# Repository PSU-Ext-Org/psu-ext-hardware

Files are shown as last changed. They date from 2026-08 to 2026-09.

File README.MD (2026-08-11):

<h1 align="center">PSU-EXT Hardware</h1>

<p align="center">
  An open-hardware inline extension that adds measurement, protection, and
  programmable control to an existing bench power supply.
</p>

<p align="center">
  
  
  
  
</p>

> **EVT prototype:** PSU-EXT is an engineering-validation design, not a
> finished or certified consumer product. It extends a bench PSU; it is not a
> standalone power supply. Use it only within the stated ratings and with
> appropriate laboratory safety practices.

<p align="center">
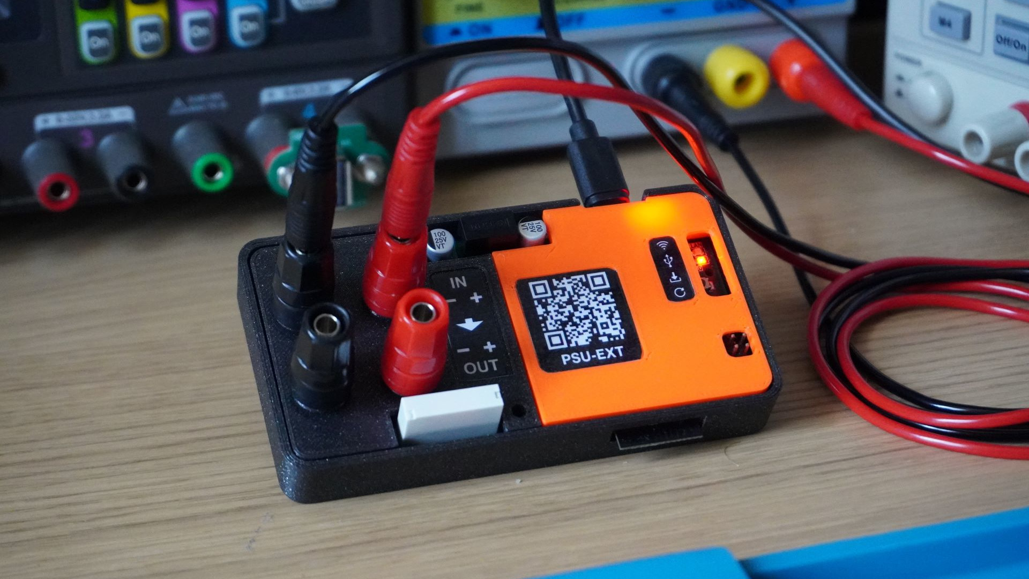
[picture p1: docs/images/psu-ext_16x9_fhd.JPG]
PSU-EXT prototype
  
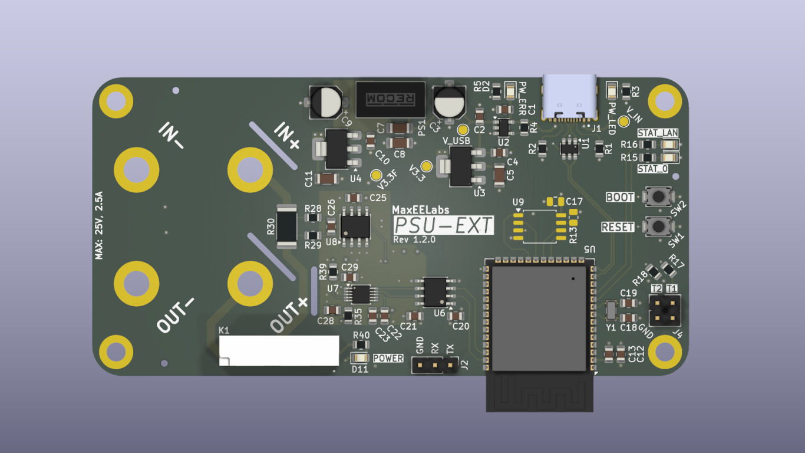
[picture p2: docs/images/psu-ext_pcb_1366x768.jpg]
PSU-EXT PCB render
  
</p>

## What it does

PSU-EXT sits between a bench power supply and a load or device under test. It
measures output voltage and current, controls the output path with a relay, and
makes the setup easier to monitor and automate.

- Live voltage, current, and power telemetry
- Relay-controlled output enable/disable
- Galvanically isolated control and measurement domains
- SCPI control over USB CDC and TCP through the companion firmware and software
- External trigger inputs, timer support, and configurable OVP/OCP behaviour

## Hardware at a glance

> **Warning:** PSU-EXT does not provide reverse-polarity protection. Verify
> supply and load polarity before connecting the device.

| Item | Details |
| --- | --- |
| Operating range | 0–25 V, 0–2.5 A |
| Board size | 100 × 50 mm (3.94 × 1.97 in) |
| Control connection | USB-C for power and data |
| Controller | Espressif ESP32-S3 |
| Measurement | ADS1115 ADC and INA240 current-sense front end |
| Isolation | Isolated I²C and isolated DC-DC power for the measurement domain |

## Repository contents

- [`electronics/`](electronics/) — KiCad schematics, PCB, libraries, and the
  [schematic PDF export](electronics/exports/schematic.pdf)
- [`mechanical/`](mechanical/) — FreeCAD enclosure design and label artwork
- [`manufacturing/`](manufacturing/) — Gerbers, BOM, and pick-and-place (CPL)
  files for fabrication and assembly
- [`THIRD-PARTY-NOTICES.md`](THIRD-PARTY-NOTICES.md) — attribution and licence
  information for bundled library assets

The design was created with [**FreeCAD 1.1.1**](https://www.freecad.org/) and
[**KiCad 10.0.1**](https://www.kicad.org/).

## Related PSU-EXT projects

- [PSU-EXT Root](https://github.com/PSU-Ext-Org/psu-ext)
- [Firmware](https://github.com/PSU-Ext-Org/psu-ext-firmware)
- [Control software](https://github.com/PSU-Ext-Org/psu-ext-software)

## Licence

Original PSU-EXT hardware design sources are licensed under the
[CERN Open Hardware Licence Version 2 - Strongly Reciprocal](LICENCE)
(CERN-OHL-S v2). The source location is
<https://github.com/PSU-Ext-Org/psu-ext>.

Some library assets are separately licensed. See [NOTICE](NOTICE),
[THIRD-PARTY-NOTICES.md](THIRD-PARTY-NOTICES.md), and
[LICENSES/dep5](LICENSES/dep5) before copying or modifying them.

Changes to the design are recorded in [CHANGES.txt](CHANGES.txt).

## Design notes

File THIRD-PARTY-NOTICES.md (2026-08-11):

# Third-Party Notices

This document identifies library assets that are not licensed under CERN-OHL-S
v2. They remain under their stated licences. The PSU-EXT KiCad design that uses
these assets is licensed under CERN-OHL-S v2.

## OSHW gear-logo bundle

| Files | Copyright and source | Licence |
|---|---|---|
| `electronics/lib/external/footprints-oshw.pretty/logo_oshw_22x13.2mm.kicad_mod` | Macklin Chaffee, 2011. [Open Source Hardware Logo — OSHWA](https://oshwa.org/resources/open-source-hardware-logo/) | [CC BY-SA 4.0](https://creativecommons.org/licenses/by-sa/4.0/) |

The OSHW gear logo may be used only for hardware that complies with the Open
Source Hardware Definition. It is not the OSHWA Certification Mark.

## SnapEDA / SnapMagic bundles

The four bundles below contain nine distributed SnapMagic Design Files: one
shared KiCad symbol-library file, four footprint files, and four STEP model
files. This repository must not add another SnapMagic Design File without prior
written permission from SnapMagic.

All listed SnapMagic Design Files are licensed under
[CC BY-SA 4.0](https://creativecommons.org/licenses/by-sa/4.0/) with the
[SnapMagic Design Exception 1.0](https://www.snapeda.com/about/terms/).
Attribution: SnapMagic Search and the applicable component manufacturer. The
Design Exception permits the combined PSU-EXT circuit-board design to be
conveyed under CERN-OHL-S v2; it does not relicense the library files.

| Bundle | Symbol | Footprint | 3D model | Source |
|---|---|---|---|---|
| Epson FC-135 32.7680KA-A0 | `electronics/lib/external/symbols-snapeda.kicad_sym` | `electronics/lib/external/footprints-snapeda.pretty/XTAL_FC-135_32.7680KA-A0.kicad_mod` | `electronics/lib/external/models-snapeda/FC-135_32.7680KA-A0.step` | <https://www.snapeda.com/parts/FC-135%2032.7680KA-A0/Epson/view-part/?ref=snap> |
| Hongfa HF49FD/005-1H12T | `electronics/lib/external/symbols-snapeda.kicad_sym` | `electronics/lib/external/footprints-snapeda.pretty/RELAY_HF49FD_005-1H12T.kicad_mod` | `electronics/lib/external/models-snapeda/005-1H12T-3DModel-STEP-56544.step` | <https://www.snapeda.com/parts/HF49FD/005-1H12T/Hongfa/view-part/?ref=snap> |
| RECOM RFM-0505S | `electronics/lib/external/symbols-snapeda.kicad_sym` | `electronics/lib/external/footprints-snapeda.pretty/CONV_RFM-0505S.kicad_mod` | `electronics/lib/external/models-snapeda/RFM-0505S.step` | <https://www.snapeda.com/parts/RFM-0505S/Recom+Power/view-part/?ref=snap> |
| HRO TYPE-C-31-M-12 | `electronics/lib/external/symbols-snapeda.kicad_sym` | `electronics/lib/external/footprints-snapeda.pretty/HRO_TYPE-C-31-M-12.kicad_mod` | `electronics/lib/external/models-snapeda/TYPE-C-31-M-12.step` | <https://www.snapeda.com/parts/TYPE-C-31-M-12/HRO+Electronics+Co.%252C+Ltd./view-part/?ref=snap> |

## MaxEELabs logo bundle

`electronics/lib/external/footprints-maxeelabs.pretty/logo_20x11.2mm.kicad_mod`
is original work of Maxim Pavlov and is excluded from CERN-OHL-S v2. It is
proprietary, with all rights reserved; no permission is granted to use, copy,
modify, distribute, or otherwise exploit the logo, subject only to rights that
cannot be excluded by law. This restriction applies only to the logo asset and
does not restrict the CERN-OHL-S v2 rights in the separate technical design
source. See the `proprietary/maxeelabs-logo` block in `LICENSES/dep5`.

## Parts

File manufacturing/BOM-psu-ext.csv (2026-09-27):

*Reference | *Manufacturer Part number | *QTY | *Original | Description | Purchase Link
R29 | 0805W8F470JT5E | 1 | Y | 47Ω ±1% 125mW 0805 Thick Film Resistor
R34 | 0805W8F1501T5E | 1 | Y | 1.5kΩ ±1% 125mW 0805 Thick Film Resistor
C10,C13,C15,C2,C20,C22,C23,C24,C26,C27,C28,C32,C33,C34,C4 | CC0805KRX7R9BB104 | 15 | Y | 100nF ±10% 50V Ceramic Capacitor X7R 0805
R35 | 0805W8F100JT5E | 1 | Y | 10Ω ±1% 125mW 0805 Thick Film Resistor
R10,R11,R18,R28,R5 | 0805W8F1002T5E | 5 | Y | 10kΩ ±1% 125mW 0805 Thick Film Resistor
R25 | 25121WF100MT4E | 1 | Y | 10mΩ 1W 200V Thick Film Resistor ±1500ppm/℃ ±1% 2512 Chip Resistor - Surface Mount RoHS
C30,C31 | CL21B103KBANNNC | 2 | Y | 10nF ±10% 50V Ceramic Capacitor X7R 0805
C11,C5 | CL31A106KBHNNNE | 2 | Y | 10uF ±10% 50V Ceramic Capacitor X5R 1206
C12,C36,C6 | CL21A106KAYNNNE | 3 | Y | 10uF ±10% 25V Ceramic Capacitor X5R 0805
C14,C18 | CC0805JRNPO9BN120 | 2 | Y | 12pF ±5% 50V Ceramic Capacitor NP0 0805
R36,R37,R38,R39 | FRC0805J164 TS | 4 | Y | 160kΩ ±5% 125mW 0805 Thick Film Resistor
R3,R32,R4,R44,R45,R8,R9 | 0805W8F1001T5E | 7 | Y | 1kΩ ±1% 125mW 0805 Thick Film Resistor
C21 | CL21B102KBCNNNC | 1 | Y | 1nF ±10% 50V Ceramic Capacitor X7R 0805
C1,C16 | CL21B105KBFNNNE | 2 | Y | 1uF ±10% 50V Ceramic Capacitor X7R 0805
R40,R41,R42,R43 | 0805W8F2002T5E | 4 | Y | 20kΩ ±1% 125mW 0805 Thick Film Resistor
C29 | CL21B224KBFNNNE | 1 | Y | 220nF ±10% 50V Ceramic Capacitor X7R 0805
R14,R15,R16,R17,R21,R22 | 0805W8F220JT5E | 6 | Y | 22Ω ±1% 125mW 0805 Thick Film Resistor
R30 | 0805W8F2202T5E | 1 | Y | 22kΩ ±1% 125mW 0805 Thick Film Resistor
C35,C37,C38 | CL21A226MAQNNNE | 3 | Y | 22uF ±20% 25V Ceramic Capacitor X5R 0805
R31 | 0805W8J0202T5E | 1 | Y | 2kΩ ±5% 125mW 0805 Thick Film Resistor
R33 | 0805W8F3300T5E | 1 | Y | 330Ω ±1% 125mW 0805 Thick Film Resistor
C7,C8 | TCC1206COG331J102DT | 2 | Y | 330pF ±5% 1kV Ceramic Capacitor C0G 1206
R23,R24 | 0805W8F470KT5E | 2 | Y | 4.7Ω ±1% 125mW 0805 Thick Film Resistor
R12,R13,R26,R27,R6,R7 | 0805W8F4701T5E | 6 | Y | 4.7kΩ ±1% 125mW 0805 Thick Film Resistor
C3,C9 | 189RV0006 | 2 | Y | 47uF ±20% 35V Aluminum Electrolytic Capacitors 2000hrs@105℃
R1,R2 | 0805W8F5101T5E | 2 | Y | 5.1kΩ ±1% 125mW 0805 Thick Film Resistor
U8 | ADS1115IDGST | 1 | Y | I2C 2V~5.5V VSSOP-10-0.5mm Analog to Digital Converters (ADC) RoHS
U2 | AP22818BKCWT-7 | 1 | Y | 1 Active Low 2A High Side Switch TSOT-23-5 Power Distribution Switches, Load Drivers RoHS
J3 | 2.54-1*3P | 1 | Y | Pin Header 3 Position 2.54mm Pitch Single Row Through Hole -40℃~+105℃
J2 | 2.54-2*3P | 1 | Y | Pin Header 6 Position 2.54mm Pitch Dual Row Through Hole
D5,D6,D7,D8 | ESD5Z3.3T1G | 4 | Y | 14VC Clamp 11A Ipp ESD DIODE SOD-523
U5 | ESP32-S3-WROOM-1-N16R8 | 1 | Y | 2.4GHz ESP32-S3R8 On-board PCB Antenna -103.5dBm SMD,25.5x18mm RF Transceiver Modules and Modems RoHS
Y1 | FC-135R 32.7680KA-A3 | 1 | Y | Crystal 32.768kHz ±20ppm 12.5pF 50kΩ SMD3215-2P
K1 | HF49FD/005-1H12T | 1 | Y | Power Relay 1 Form A: 1A (SPST-NO) 5V Coil SIP,5x20mm
U10 | INA240A2DR | 1 | Y | 1 5uV -4V~80V 2V/us 132dB 90uA 1.8mA 50V/V SOIC-8 Instrumentation, Op Amps, Buffer Amps RoHS
U7 | ISO1540DR | 1 | Y | 50kV/us 3V~5.5V SOIC-8 Digital Isolators RoHS
U3,U4 | LD1117S33TR | 2 | Y | 3.3V Positive Fixed SOT-223 Voltage Regulators - Linear, Low Drop Out (LDO) Regulators RoHS
D3 | KT-0805G | 1 | Y | Emerald Green 525nm LED Indication - Discrete 2.6V~3.1V 0805
D4 | KT-0805W | 1 | Y | White LED Indication - Discrete 2.6V~3.2V 0805
D1,D14,D2 | NCD0805R1 | 3 | Y | Red 630nm LED Indication - Discrete 1.6V~2.6V 0805
D15 | LL4148-GS08 | 1 | Y | Diode Independent 75V 300mA Surface Mount MiniMELF
U12 | LM2664M6X/NOPB | 1 | Y | Inverted 80kHz -5.5V~-1.8V 40mA SOT-23-6 Voltage Regulators - DC DC Switching Regulators RoHS
U9 | LMV321LILT | 1 | Y | 70mA 1 7mV 600V/ms 75dB 27nA 120uA 1.3MHz Rail-to-rail output SOT-23-5 Instrumentation, Op Amps, Buffer Amps RoHS
Q1 | MMBT2222A 1P | 1 | Y | Bipolar (BJT) Transistor NPN 40V 600mA 300MHz 300mW Surface Mount SOT-23
PS1 | RFM-0505S | 1 | Y | Isolated Module DC DC Converter 1 Output 5V 200mA 5V Input
D13 | SMBJ36A | 1 | Y | 58.1VC Clamp 10.4A@10/1000us Ipp TVS DIODE DO-214AA(SMB)
SW1,SW2 | TS-1088-AR02016 | 2 | Y | Tactile Switch SPST 160gf 2mm SMD (SMT) Tab 4mm x 3mm Surface Mount
U11 | TSZ122IYDT | 1 | Y | 7mA 2 1uV 0.19V/us 122dB 70pA 28uA 400kHz Rail-to-Rail Input, Rail-to-Rail Output SO-8 Instrumentation, Op Amps, Buffer Amps RoHS
J1 | TYPE-C-31-M-12 | 1 | Y | USB-C (USB TYPE-C) Receptacle Connector 16 Position Surface Mount
U1 | USBLC6-2SC6 | 1 | Y | 15VC Clamp ESD DIODE SOT-23-6

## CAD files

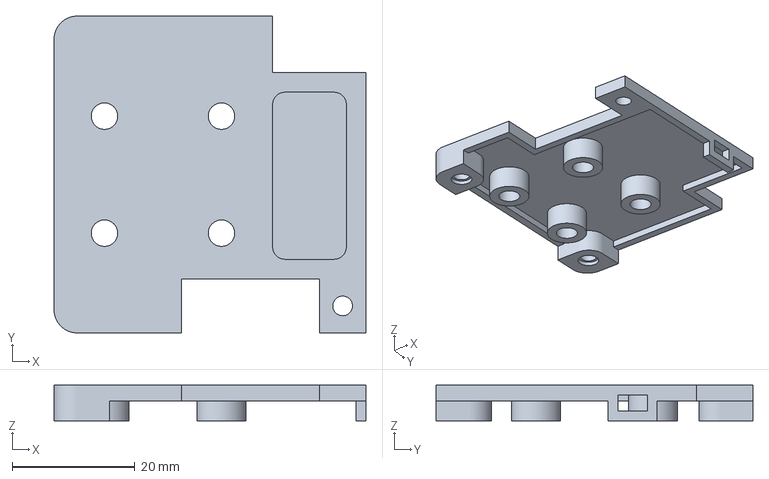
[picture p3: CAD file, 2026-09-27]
mechanical/enclosure/exports/housingcover-top-right.3mf
50.8 x 51.6 x 5.80 mm

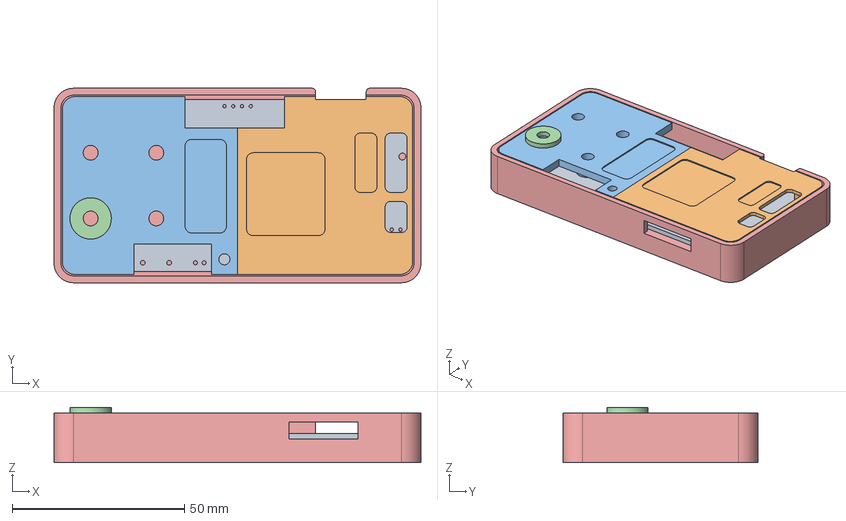
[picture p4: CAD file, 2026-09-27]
mechanical/enclosure/psu-ext-enclosure.FCStd
106.4 x 56.4 x 16.0 mm
Pcb_f07c
cover-top-left
cover-top-right
terminal-nut
bs-joined-frame-bottom

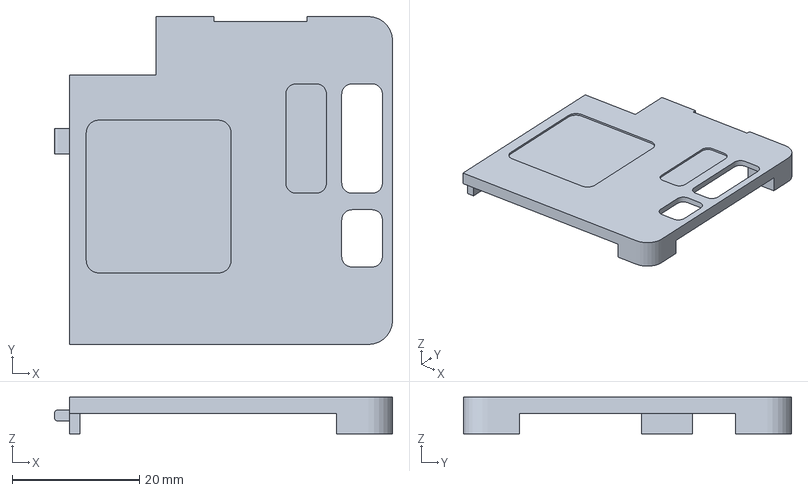
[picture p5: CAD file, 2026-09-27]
mechanical/enclosure/exports/housingcover-top-left.3mf
53.2 x 51.6 x 5.80 mm

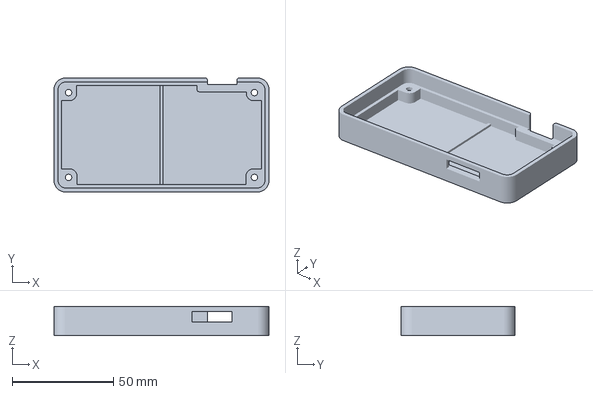
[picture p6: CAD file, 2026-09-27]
mechanical/enclosure/exports/bs-joined-frame-bottom.3mf
106.4 x 56.4 x 14.4 mm

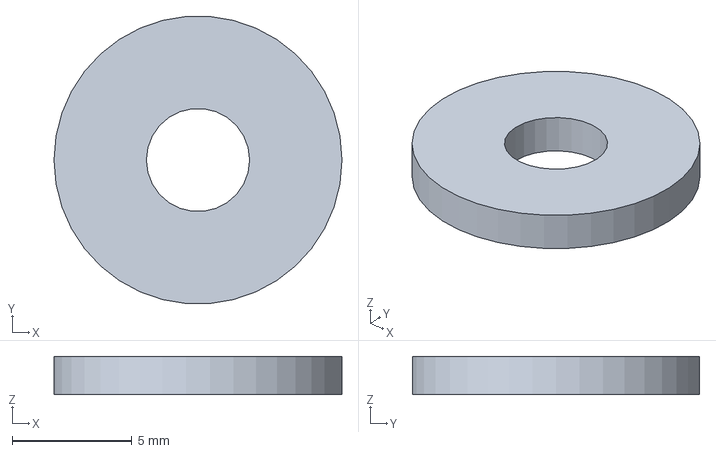
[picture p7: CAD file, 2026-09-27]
mechanical/enclosure/exports/terminal-nut.3mf
12.0 x 12.0 x 1.60 mm

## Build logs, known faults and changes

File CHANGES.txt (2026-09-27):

PSU-EXT change record
=====================

When publishing a modification, add (do not remove) a dated, brief description
of each design change. This supports CERN-OHL-S v2 section 3.3(b).

2026-08-09 v. 1.2.0: Added repository licensing, ownership, and third-party dependency
notices for the public CERN-OHL-S v2 release.

2026-08-15 v. 1.2.1: 
- Added low impedance offset to INA240A2, using resistor divider and
LM321, small offset would allow correct current measurments between 0 and 5 mA, alternativelty
by seting offset to 3V one can measure current into 2 directions but with less resolution.
- Marked C16 - IO0 debounce cap as do-not-populate as it forces ESP32 into download mode on 
first start

2026-09-09 v. 1.3.0 (work in progress):
- Added input buffering and a negative rail for near-zero measurements.
- Split the front end into ADC/current and voltage schematic sheets and updated
  the PCB and project configuration.
- Added the MaxEELabs symbol library, with copyright and CERN-OHL-S v2 license
  information recorded separately in LICENSES/dep5.

Work in progress: the generated outputs still need to be updated.
- TODO: Update the BOM.
- TODO: Update the CPL (pick-and-place file).
- TODO: Update the schematic export.
- TODO: Update the Gerbers.

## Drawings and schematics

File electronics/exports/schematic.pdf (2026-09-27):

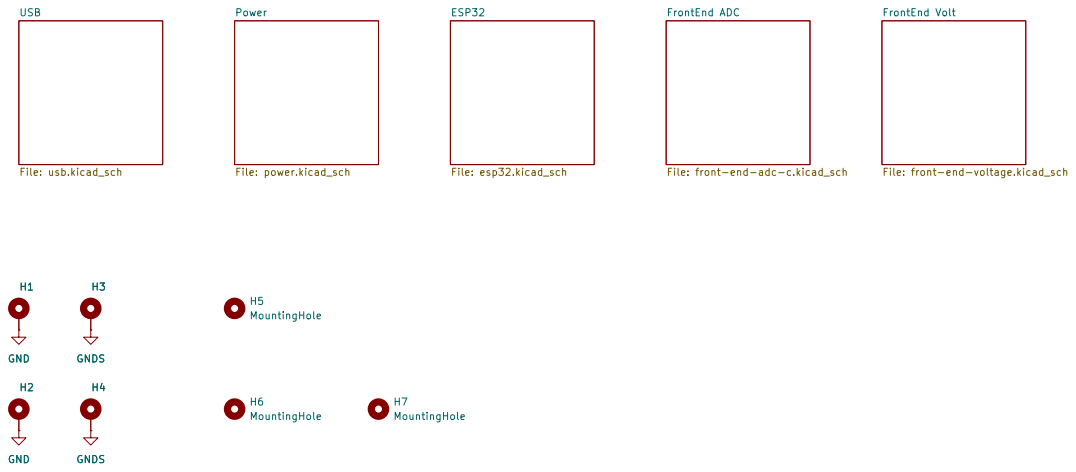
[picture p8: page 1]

File: front-end-adc-c.kicad_sch Power File: power.kicad_sch USB

FrontEnd Volt File: front-end-voltage.kicad_sch

This hardware design is licensed under CERN-OHL-S v2.
Copyright © 2026 PSU-EXT Authors: https://github.com/PSU-Ext-Org

MaxEELabs
Sheet: /
File: psu-ext.kicad_sch
Title: PSU-EXT Root

Size: A4 | Rev: 1.3.0
KiCad E.D.A. 10.0.6 | Id: 1/6

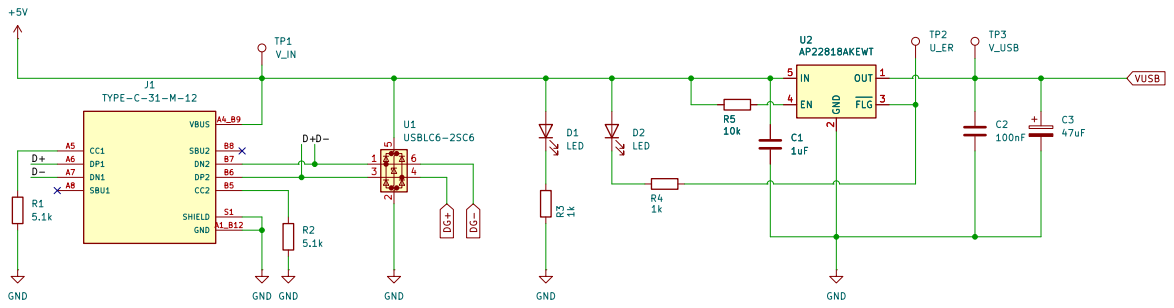
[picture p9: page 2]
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

MaxEELabs
Sheet: /USB/
File: usb.kicad_sch
Title: PSU-EXT USB

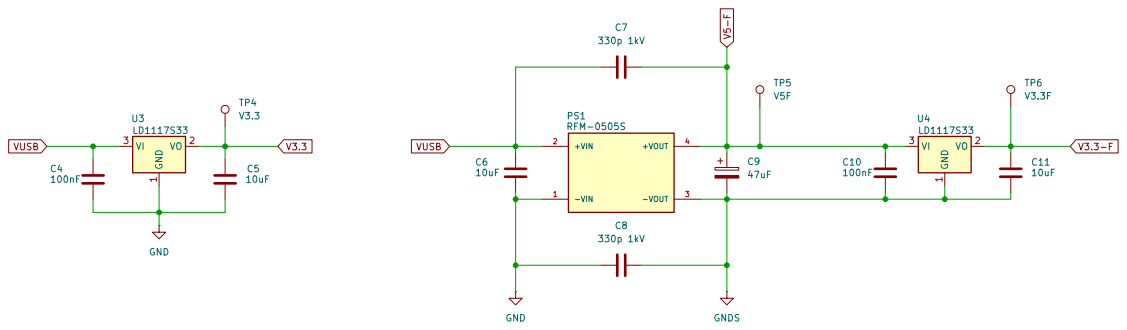
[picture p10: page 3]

Copyright © 2026 PSU-EXT Authors: https://github.com/PSU-Ext-Org GND
10uF GND

This hardware design is licensed under CERN-OHL-S v2.

MaxEELabs
Sheet: /Power/
File: power.kicad_sch
Title: PSU-EXT Power

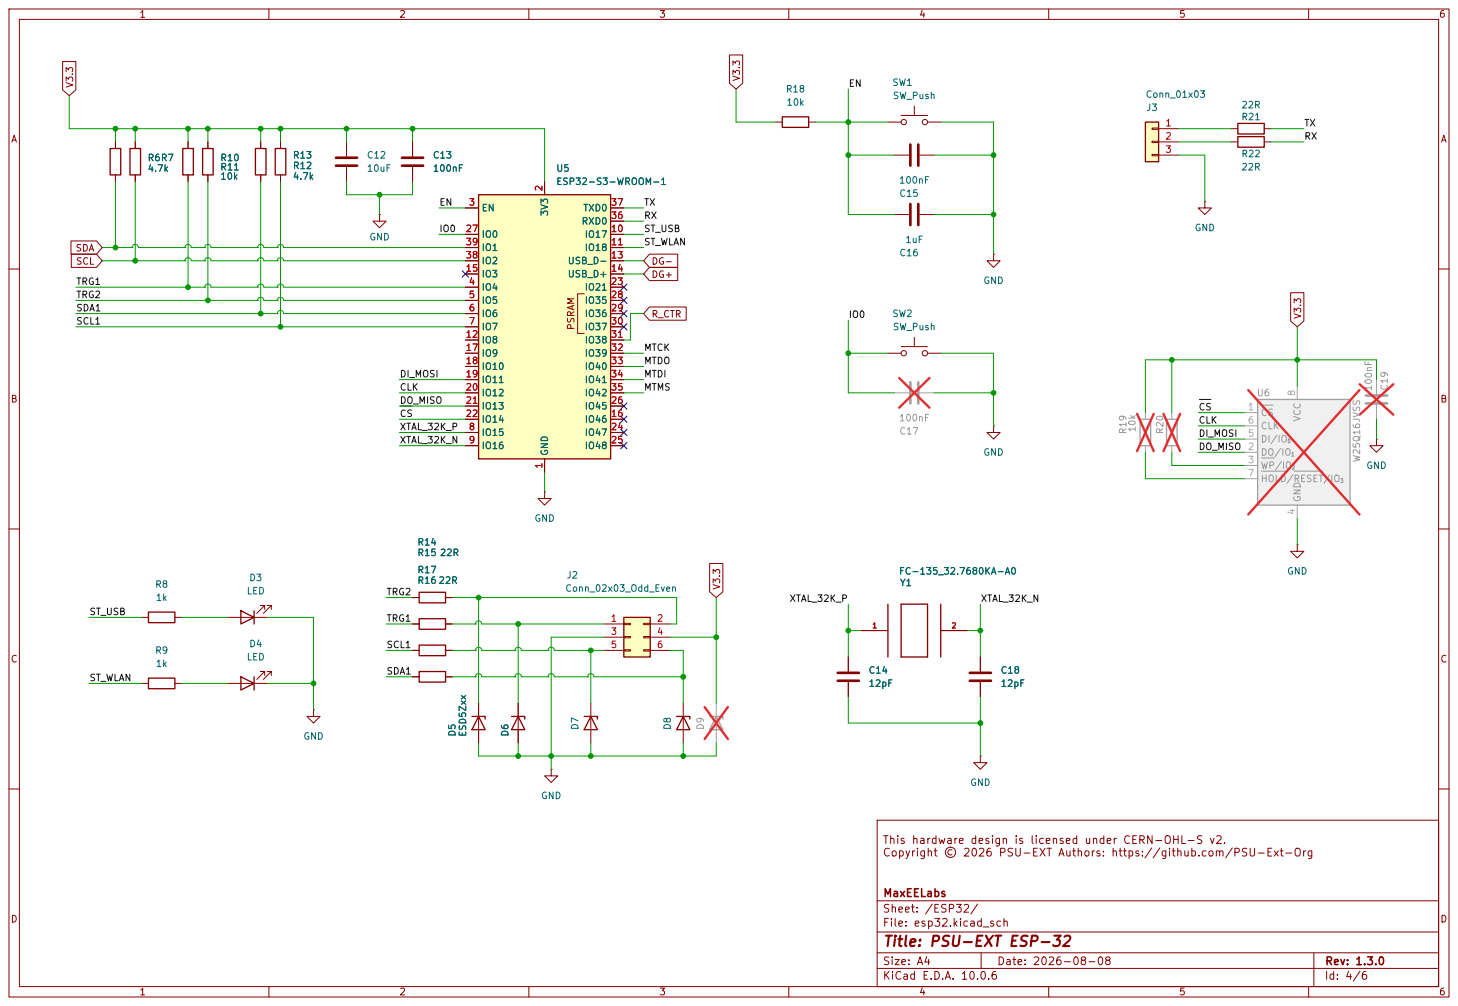
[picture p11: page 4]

4 DI/IO0 5 CLK 6 HOLD/RESET/IO3 7 VCC U6 8 W25Q16JVSS

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

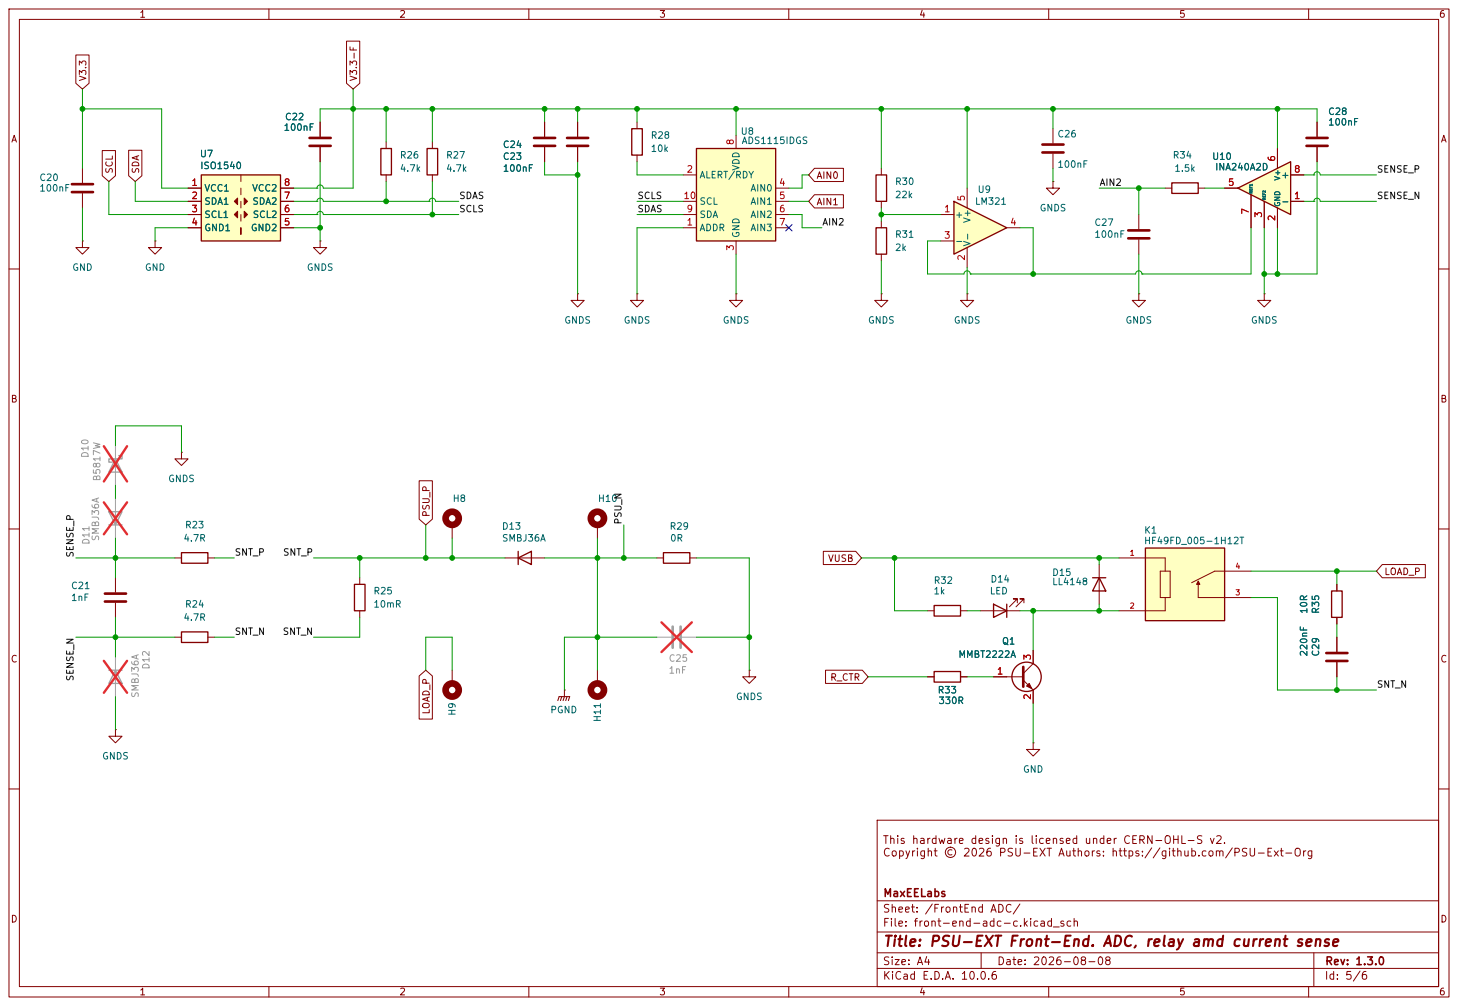
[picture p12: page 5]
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

MaxEELabs
Sheet: /FrontEnd ADC/
File: front-end-adc-c.kicad_sch
Title: PSU-EXT Front-End. ADC, relay amd current sense

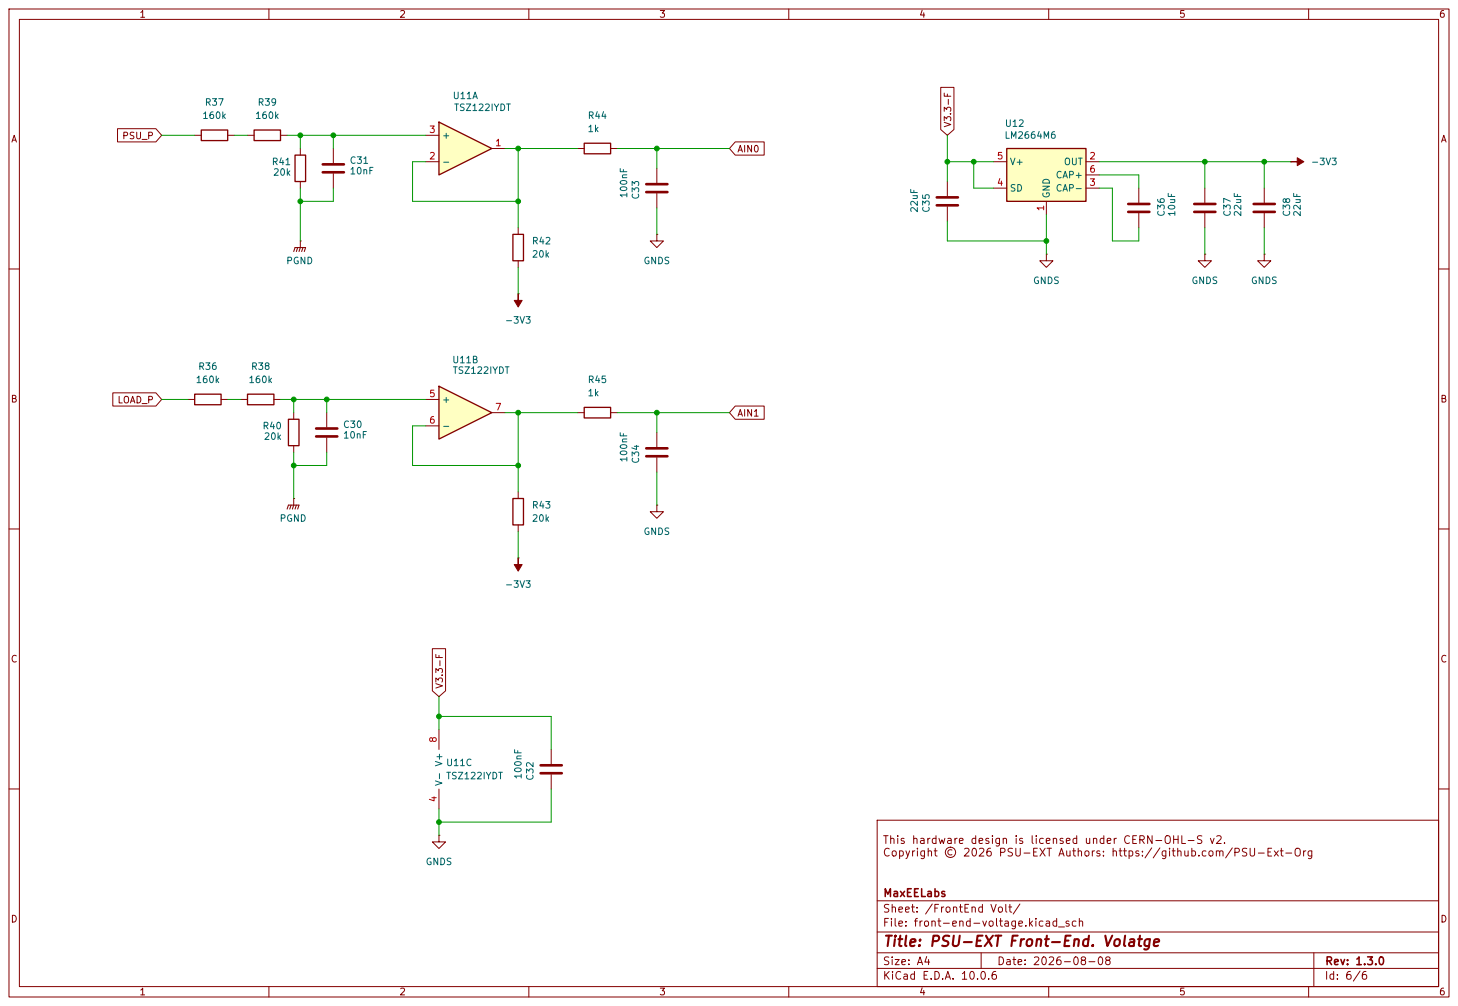
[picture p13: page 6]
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

MaxEELabs
Sheet: /FrontEnd Volt/
File: front-end-voltage.kicad_sch
Title: PSU-EXT Front-End. Volatge

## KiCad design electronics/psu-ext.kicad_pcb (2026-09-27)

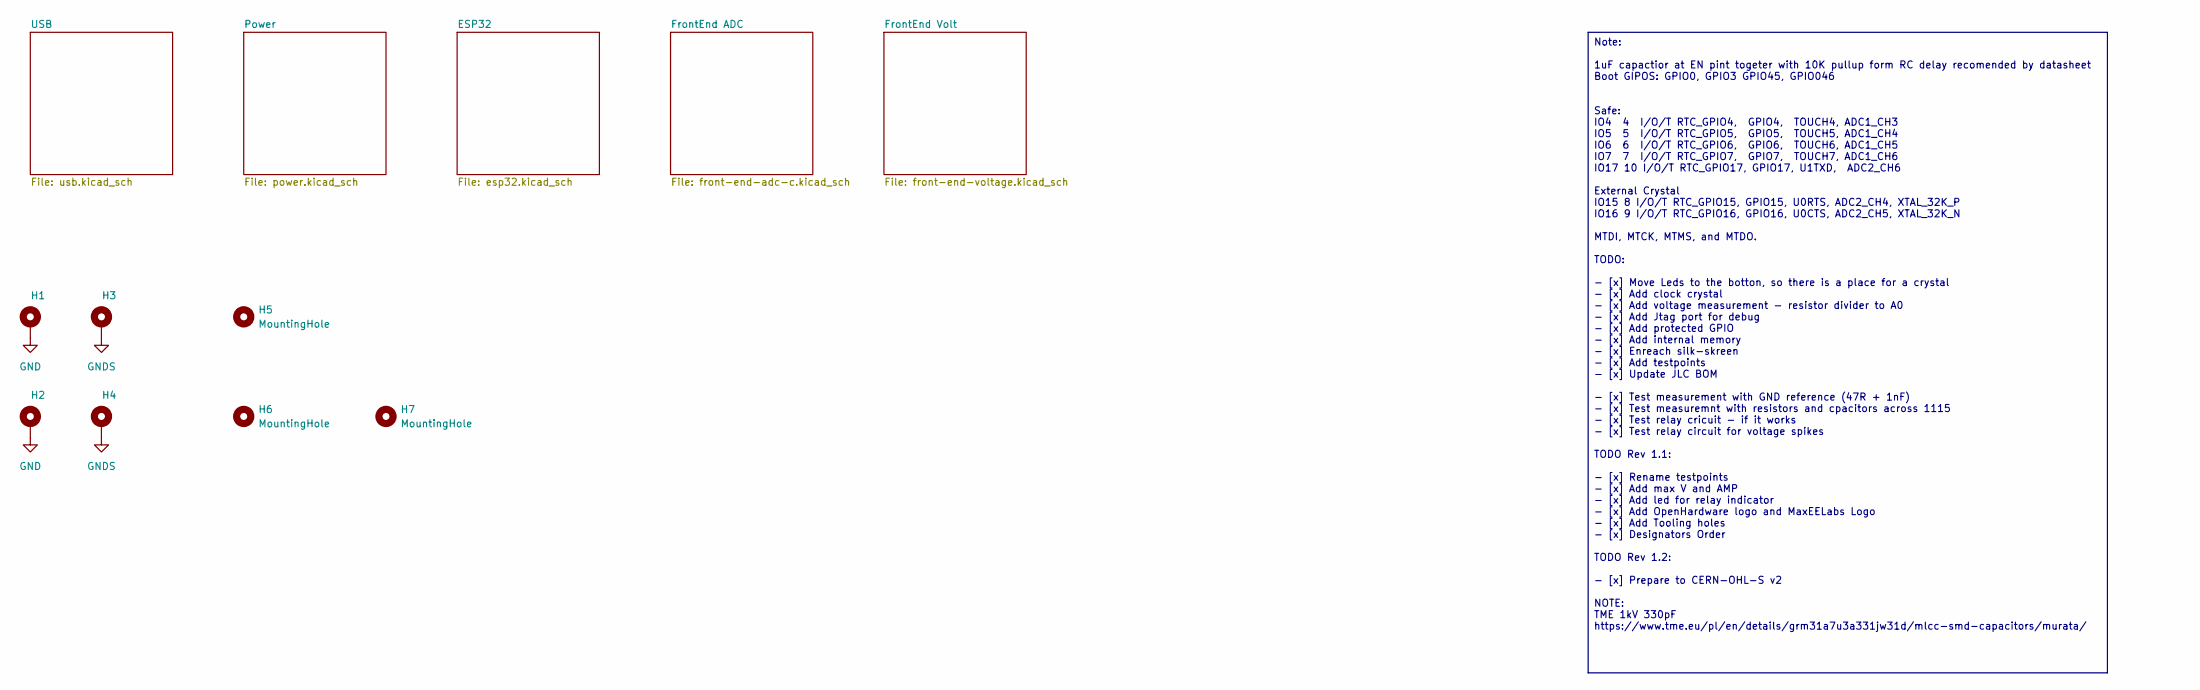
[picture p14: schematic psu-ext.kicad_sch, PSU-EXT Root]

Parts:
H1, H2, H3, H4: MountingHole_Pad; MountingHole_3.2mm_M3_ISO7380_Pad
H5, H6, H7: MountingHole; ToolingHole_1.152mm

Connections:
GND: H1.1 (1_1), H2.1 (1_1); also elsewhere on the board
GNDS: H3.1 (1_1), H4.1 (1_1); also elsewhere on the board

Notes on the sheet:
Note: 1uF capactior at EN pint togeter with 10K pullup form RC delay recomended by datasheet Boot GIPOS: GPIO0, GPIO3 GPIO45, GPIO046 Safe: IO4 4 I/O/T RTC_GPIO4, GPIO4, TOUCH4, ADC1_CH3 IO5 5 I/O/T RTC_GPIO5, GPIO5, TOUCH5, ADC1_CH4 IO6 6 I/O/T RTC_GPIO6, GPIO6, TOUCH6, ADC1_CH5 IO7 7 I/O/T RTC_GP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

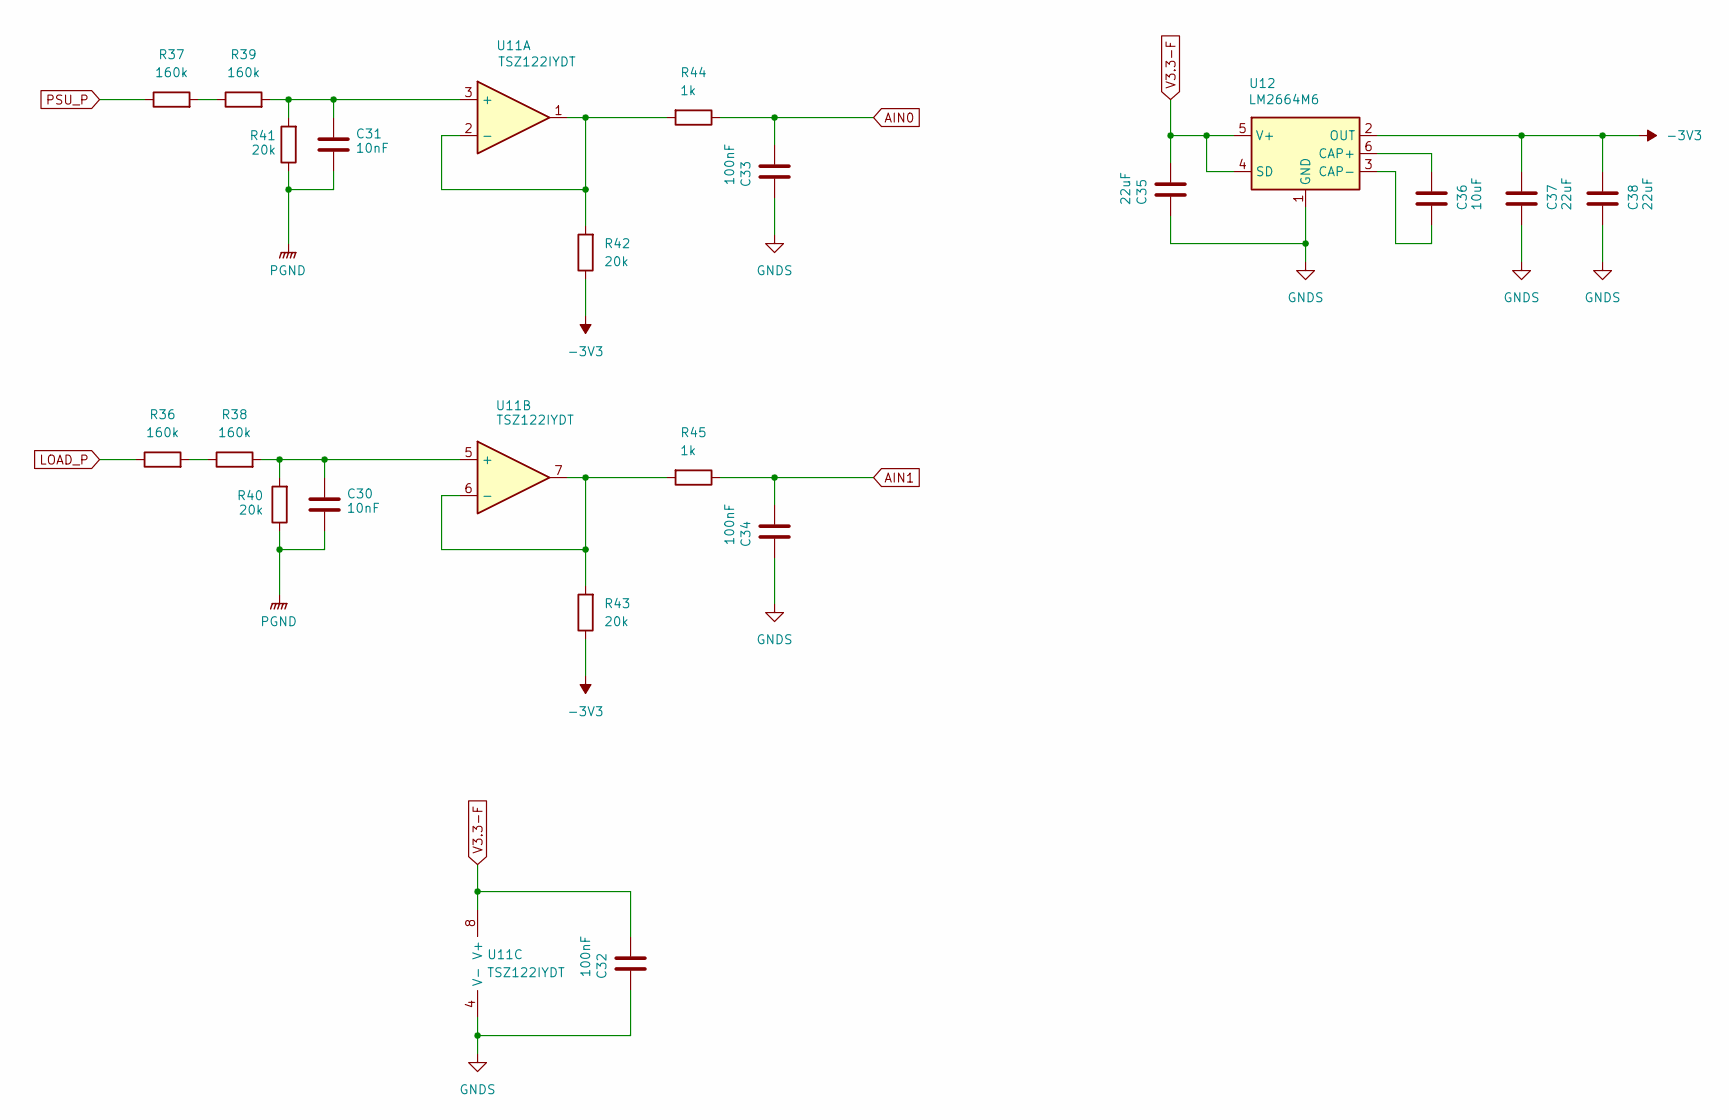
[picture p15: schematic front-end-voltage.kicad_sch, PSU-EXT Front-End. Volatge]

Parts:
C30, C31: 10nF; C_0805_2012Metric
C32, C33, C34: 100nF; C_0805_2012Metric
C35, C37, C38: 22uF; C_0805_2012Metric
C36: 10uF; C_0805_2012Metric
R36, R37, R38, R39: 160k; R_0805_2012Metric
R40, R41, R42, R43: 20k; R_0805_2012Metric
R44, R45: 1k; R_0805_2012Metric
U11: TSZ122IYDT; SOIC-8_3.9x4.9mm_P1.27mm
U12: LM2664M6; SOT-23-6

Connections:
-3V3: C37.1, C38.1, R42.1, R43.1, U12.2 (OUT)
AIN0: C33.1, R44.1; also elsewhere on the board
AIN1: C34.1, R45.1; also elsewhere on the board
GNDS: C32.2, C33.2, C34.2, C35.2, C37.2, C38.2, U11.4 (V-), U12.1 (GND); also elsewhere on the board
LOAD_P: R36.1; also elsewhere on the board
unnamed: R36.2, R38.1
unnamed: R37.2, R39.1
unnamed: C31.1, R39.2, R41.2, U11.3 (+)
unnamed: R42.2, R44.2, U11.1, U11.2 (-)
unnamed: C30.1, R38.2, R40.2, U11.5 (+)
unnamed: R43.2, R45.2, U11.6 (-), U11.7
unnamed: C36.1, U12.6 (CAP+)
unnamed: C36.2, U12.3 (CAP-)
PGND: C30.2, C31.2, R40.1, R41.1; also elsewhere on the board
PSU_P: R37.1; also elsewhere on the board
V3.3-F: C32.1, C35.1, U11.8 (V+), U12.4 (SD), U12.5 (V+); also elsewhere on the board

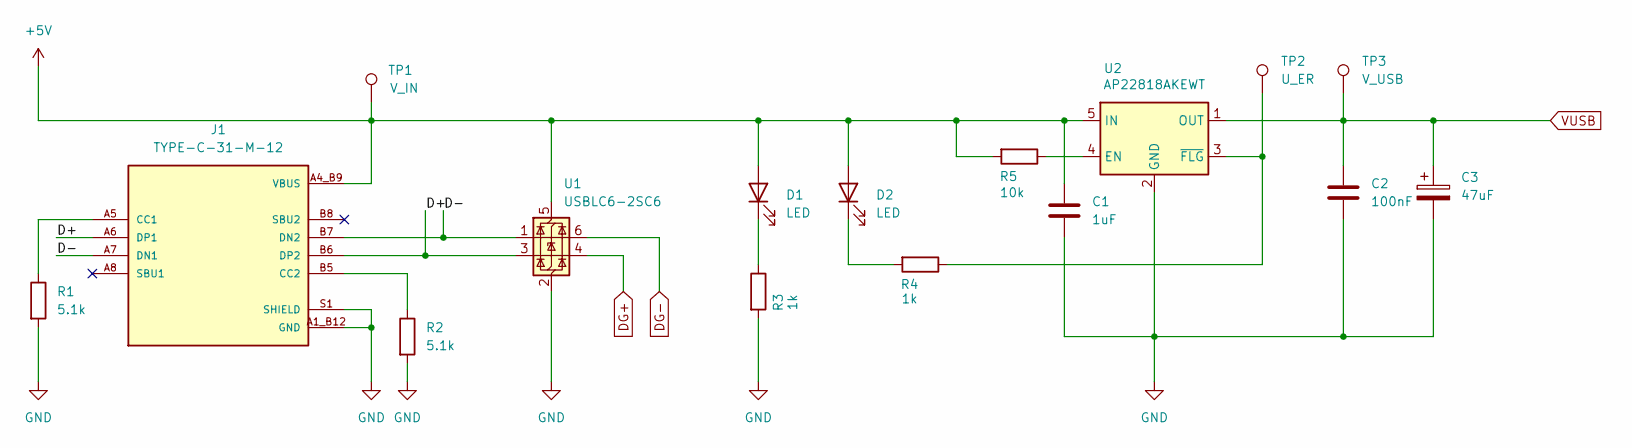
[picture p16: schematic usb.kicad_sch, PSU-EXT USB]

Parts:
C1: 1uF; C_0805_2012Metric
C2: 100nF; C_0805_2012Metric
C3: 47uF; CP_Elec_5x5.9
D1, D2: LED; LED_0805_2012Metric
J1: TYPE-C-31-M-12; HRO_TYPE-C-31-M-12; PARTREV 2020.12.08
R1, R2: 5.1k; R_0805_2012Metric
R3, R4: 1k; R_0805_2012Metric
R5: 10k; R_0805_2012Metric
TP1: V_IN; TestPoint_Pad_D1.5mm
TP2: U_ER; TestPoint_Pad_D1.5mm
TP3: V_USB; TestPoint_Pad_D1.5mm
U1: USBLC6-2SC6; SOT-23-6
U2: AP22818AKEWT; SOT-23-5

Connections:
+5V: C1.1, D1.2 (A), D2.2 (A), J1.A4_B9 (VBUS), J1.B4_A9 (VBUS), R5.2, TP1.1 (1_1), U1.5 (VBUS), U2.5 (IN)
/USB/D+: J1.A6 (DP1), J1.B6 (DP2), U1.3 (I/O2)
/USB/D-: J1.A7 (DN1), J1.B7 (DN2), U1.1 (I/O1)
DG+: U1.4 (I/O2); also elsewhere on the board
DG-: U1.6 (I/O1); also elsewhere on the board
GND: C1.2, C2.2, C3.2, J1.A1_B12 (GND), J1.B1_A12 (GND), J1.S1 (SHIELD), J1.S2 (SHIELD), J1.S3 (SHIELD), J1.S4 (SHIELD), R1.2, R2.2, R3.2, U1.2 (GND), U2.2 (GND); also elsewhere on the board
unnamed: D1.1 (K), R3.1
unnamed: D2.1 (K), R4.2
unnamed: J1.A5 (CC1), R1.1
unnamed: J1.B5 (CC2), R2.1
unnamed: R5.1, U2.4 (EN)
unnamed: R4.1, TP2.1 (1_1), U2.3 (~FLG)
VUSB: C2.1, C3.1, TP3.1 (1_1), U2.1 (OUT); also elsewhere on the board

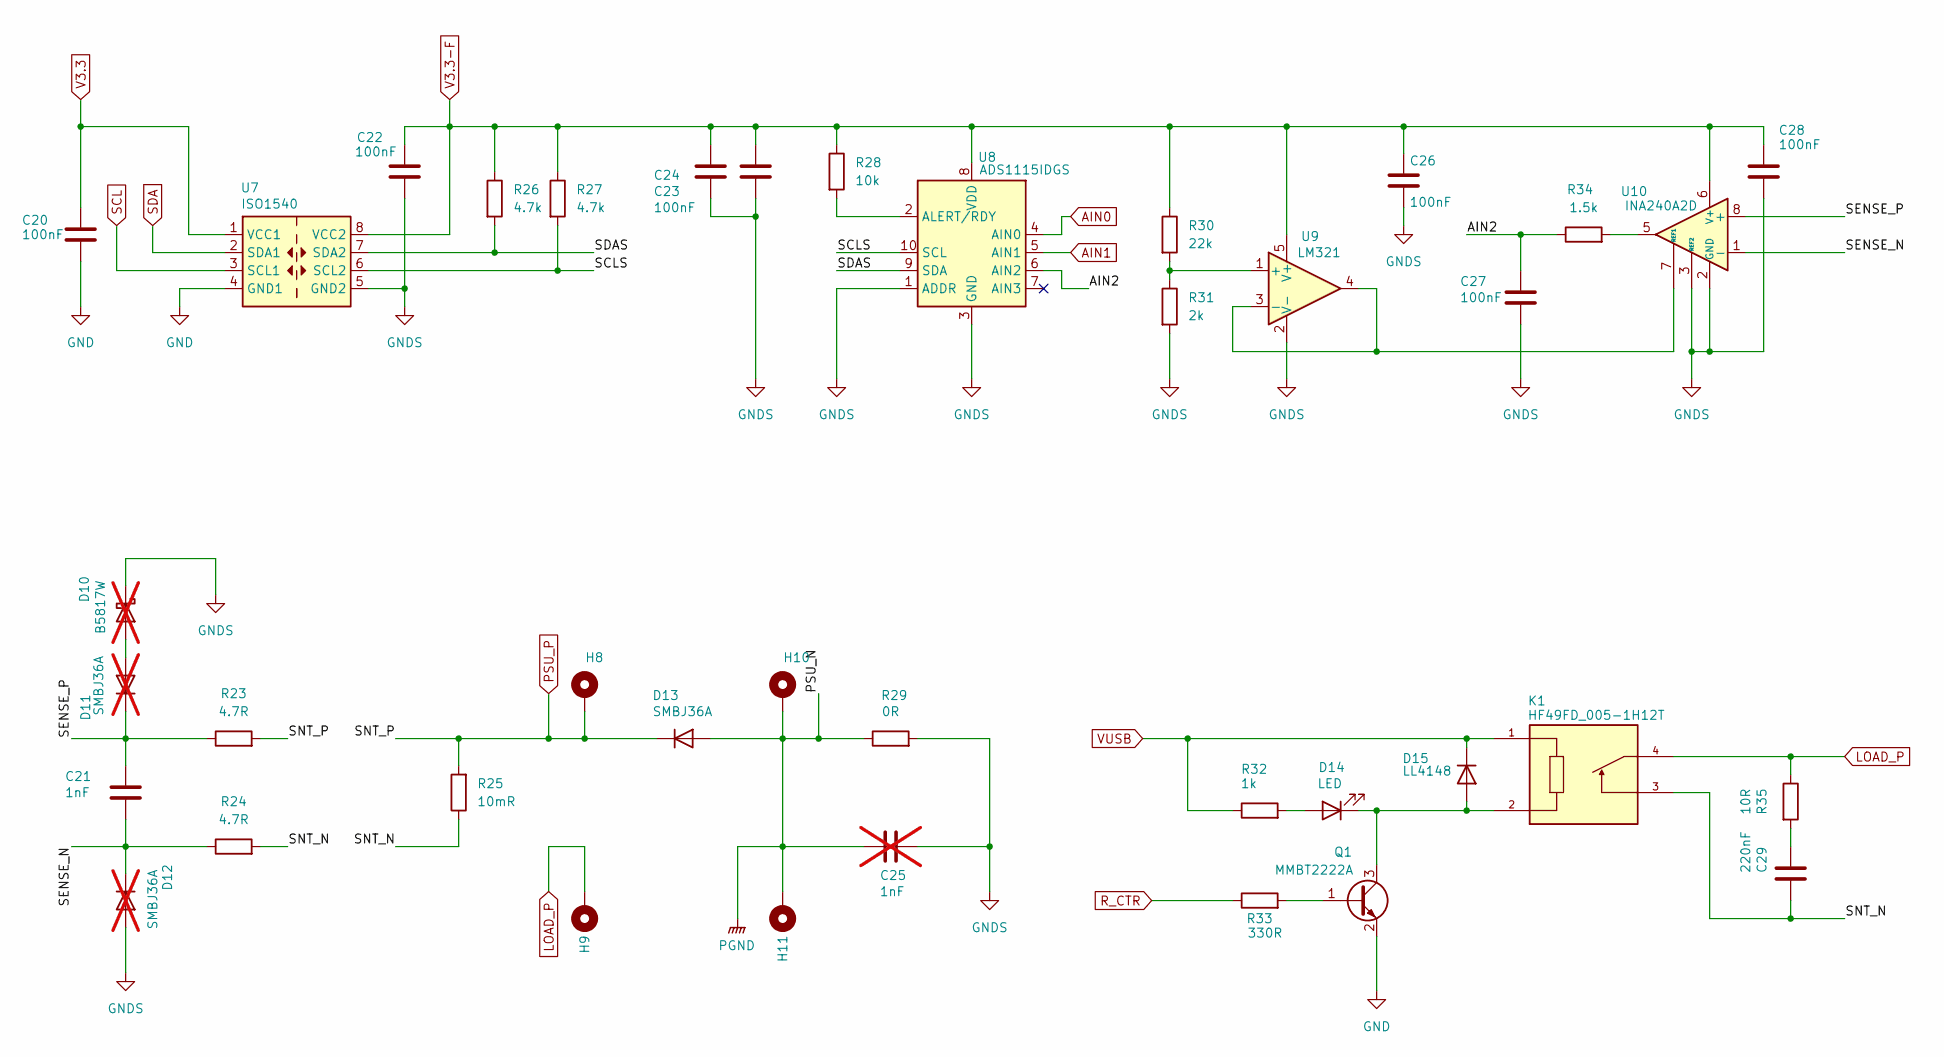
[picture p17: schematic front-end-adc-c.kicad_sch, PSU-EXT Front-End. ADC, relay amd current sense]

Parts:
C20, C22, C23, C24, C26, C27, C28: 100nF; C_0805_2012Metric
C21: 1nF; C_0805_2012Metric
C25: 1nF; C_0805_2012Metric; not fitted
C29: 220nF; C_0805_2012Metric
D10: B5817W; Nexperia_CFP3_SOD-123W; not fitted
D11, D12: SMBJ36A; D_SMB; not fitted
D13: SMBJ36A; D_SMB
D14: LED; LED_0805_2012Metric
D15: LL4148; D_MiniMELF
H8, H9, H10, H11: MountingHole_Pad; MountingHole_4.3mm_M4_ISO7380_Pad
K1: HF49FD_005-1H12T; RELAY_HF49FD_005-1H12T; PARTREV 1.13
Q1: MMBT2222A; SOT-23
R23, R24: 4.7R; R_0805_2012Metric
R25: 10mR; R_2512_6332Metric_Pad1.40x3.35mm_HandSolder
R26, R27: 4.7k; R_0805_2012Metric
R28: 10k; R_0805_2012Metric
R29: 0R; R_0805_2012Metric
R30: 22k; R_0805_2012Metric
R31: 2k; R_0805_2012Metric
R32: 1k; R_0805_2012Metric
R33: 330R; R_0805_2012Metric
R34: 1.5k; R_0805_2012Metric
R35: 10R; R_0805_2012Metric
U7: ISO1540; SOIC-8_3.9x4.9mm_P1.27mm
U8: ADS1115IDGS; TSSOP-10_3x3mm_P0.5mm
U9: LM321; SOT-23-5
U10: INA240A2D; SOIC-8_3.9x4.9mm_P1.27mm

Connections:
/FrontEnd ADC/AIN2: C27.1, R34.1, U8.6 (AIN2)
/FrontEnd ADC/SCLS: R27.2, U7.6 (SCL2), U8.10 (SCL)
/FrontEnd ADC/SDAS: R26.2, U7.7 (SDA2), U8.9 (SDA)
/FrontEnd ADC/SENSE_N: C21.2, D12.1 (K), R24.1, U10.1 (-)
/FrontEnd ADC/SENSE_P: C21.1, D11.1 (K), R23.1, U10.8 (+)
/FrontEnd ADC/SNT_N: C29.2, K1.3, R24.2, R25.1
AIN0: U8.4 (AIN0); also elsewhere on the board
AIN1: U8.5 (AIN1); also elsewhere on the board
GND: C20.2, Q1.2 (E), U7.4 (GND1); also elsewhere on the board
GNDS: C22.2, C23.2, C24.2, C25.2, C26.2, C27.2, C28.2, D10.1 (K), D12.2 (A), R29.2, R31.2, U7.5 (GND2), U8.1 (ADDR), U8.3 (GND), U9.2 (V-), U10.2 (GND), U10.3 (REF2), U10.4 (GND); also elsewhere on the board
LOAD_P: H9.1 (1_1), K1.4, R35.1; also elsewhere on the board
unnamed: C29.1, R35.2
unnamed: D10.2 (A), D11.2 (A)
unnamed: D14.2 (A), R32.2
unnamed: D14.1 (K), D15.2 (A), K1.2, Q1.3 (C)
unnamed: Q1.1 (B), R33.2
unnamed: R34.2, U10.5
unnamed: R28.2, U8.2 (ALERT/RDY)
unnamed: R30.2, R31.1, U9.1 (+)
unnamed: U9.3 (-), U9.4, U10.7 (REF1)
PGND: C25.1, D13.2 (A), H10.1 (1_1), H11.1 (1_1), R29.1; also elsewhere on the board
PSU_P: D13.1 (K), H8.1 (1_1), R23.2, R25.2; also elsewhere on the board
R_CTR: R33.1; also elsewhere on the board
SCL: U7.3 (SCL1); also elsewhere on the board
SDA: U7.2 (SDA1); also elsewhere on the board
V3.3: C20.1, U7.1 (VCC1); also elsewhere on the board
V3.3-F: C22.1, C23.1, C24.1, C26.1, C28.1, R26.1, R27.1, R28.1, R30.1, U7.8 (VCC2), U8.8 (VDD), U9.5 (V+), U10.6 (V+); also elsewhere on the board
VUSB: D15.1 (K), K1.1, R32.1; also elsewhere on the board

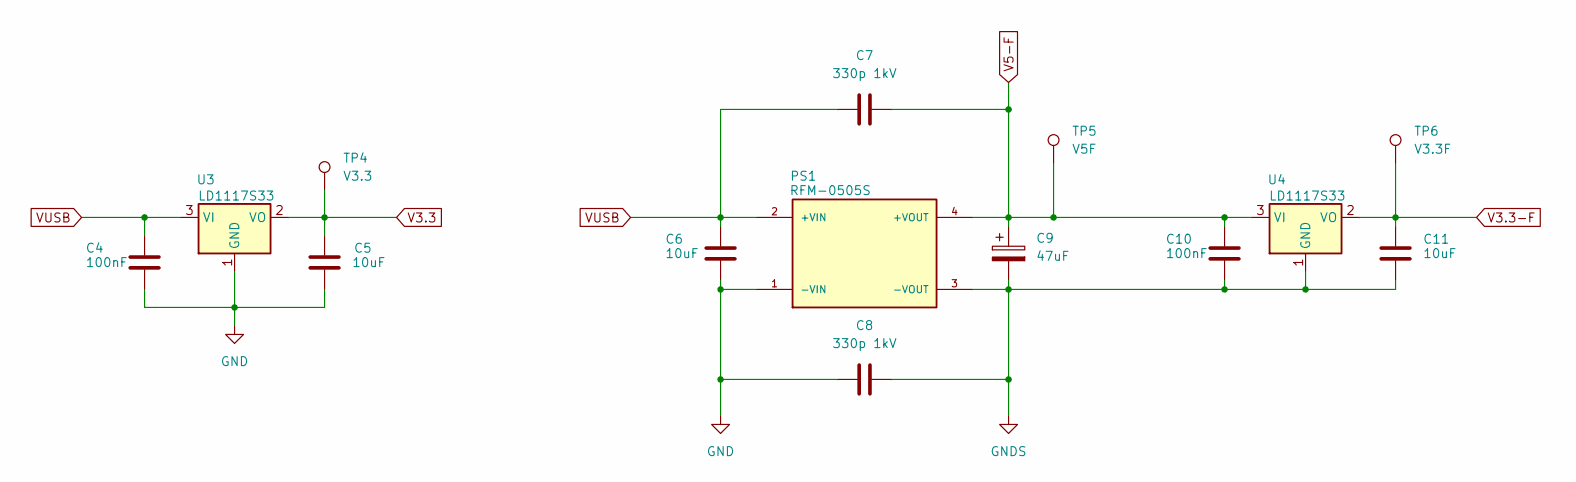
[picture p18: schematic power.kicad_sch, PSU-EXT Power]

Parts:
C4, C10: 100nF; C_0805_2012Metric
C5, C11: 10uF; C_1206_3216Metric
C6: 10uF; C_0805_2012Metric
C7, C8: 330p 1kV; C_1206_3216Metric_Pad1.33x1.80mm_HandSolder
C9: 47uF; CP_Elec_5x5.9
PS1: RFM-0505S; CONV_RFM-0505S; PARTREV 0
TP4: V3.3; TestPoint_Pad_D1.5mm
TP5: V5F; TestPoint_Pad_D1.5mm
TP6: V3.3F; TestPoint_Pad_D1.5mm
U3, U4: LD1117S33; SOT-223-3_TabPin2

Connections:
GND: C4.2, C5.2, C6.2, C8.1, PS1.1 (-VIN), U3.1 (GND); also elsewhere on the board
GNDS: C8.2, C9.2, C10.2, C11.2, PS1.3 (-VOUT), U4.1 (GND); also elsewhere on the board
V3.3: C5.1, TP4.1 (1_1), U3.2 (VO); also elsewhere on the board
V3.3-F: C11.1, TP6.1 (1_1), U4.2 (VO); also elsewhere on the board
V5-F: C7.2, C9.1, C10.1, PS1.4 (+VOUT), TP5.1 (1_1), U4.3 (VI)
VUSB: C4.1, C6.1, C7.1, PS1.2 (+VIN), U3.3 (VI); also elsewhere on the board

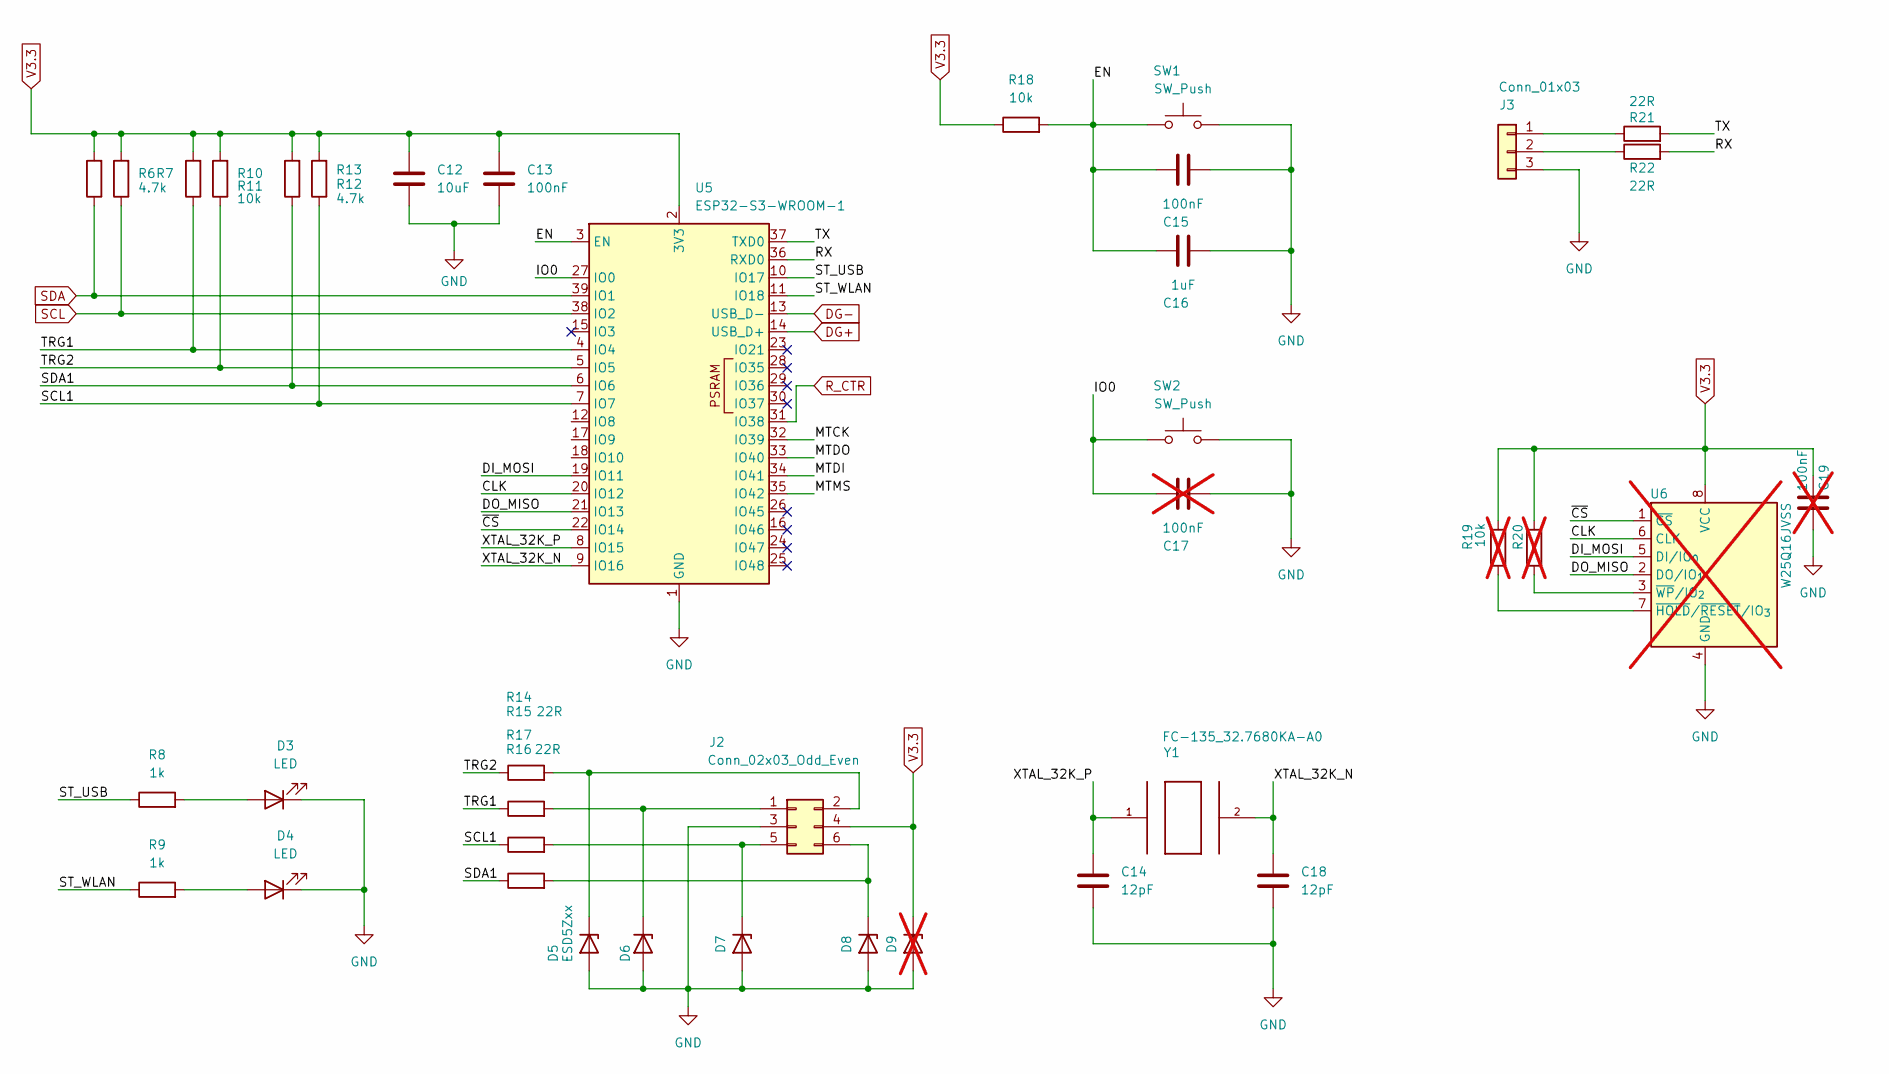
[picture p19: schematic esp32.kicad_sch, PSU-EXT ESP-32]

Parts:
C12: 10uF; C_0805_2012Metric
C13, C15: 100nF; C_0805_2012Metric
C14, C18: 12pF; C_0805_2012Metric
C16: 1uF; C_0805_2012Metric
C17, C19: 100nF; C_0805_2012Metric; not fitted
D3, D4: LED; LED_0805_2012Metric
D5, D6, D7, D8: ESD5Zxx; D_SOD-523
D9: ESD5Zxx; D_SOD-523; not fitted
J2: Conn_02x03_Odd_Even; PinHeader_2x03_P2.54mm_Vertical
J3: Conn_01x03; PinHeader_1x03_P2.54mm_Vertical
R6, R7, R12, R13: 4.7k; R_0805_2012Metric
R8, R9: 1k; R_0805_2012Metric
R10, R11, R18: 10k; R_0805_2012Metric
R14, R15, R16, R17, R21, R22: 22R; R_0805_2012Metric
R19, R20: 10k; R_0805_2012Metric; not fitted
SW1, SW2: SW_Push; SW_SPST_TS-1088-xR025
U5: ESP32-S3-WROOM-1
U6: W25Q16JVSS; SOIC-8_5.3x5.3mm_P1.27mm; not fitted
Y1: FC-135_32.7680KA-A0; XTAL_FC-135_32.7680KA-A0

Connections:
/ESP32/CLK: U5.20 (IO12), U6.6 (CLK)
/ESP32/DI_MOSI: U5.19 (IO11), U6.5 (DI/IO_{0})
/ESP32/DO_MISO: U5.21 (IO13), U6.2 (DO/IO_{1})
/ESP32/EN: C15.1, C16.1, R18.2, SW1.1, U5.3 (EN)
/ESP32/IO0: C17.1, SW2.1, U5.27 (IO0)
/ESP32/MTCK: U5.32 (IO39)
/ESP32/MTDI: U5.34 (IO41)
/ESP32/MTDO: U5.33 (IO40)
/ESP32/MTMS: U5.35 (IO42)
/ESP32/RX: R22.2, U5.36 (RXD0)
/ESP32/SCL1: R13.1, R16.1, U5.7 (IO7)
/ESP32/SDA1: R12.1, R17.1, U5.6 (IO6)
/ESP32/ST_USB: R8.1, U5.10 (IO17)
/ESP32/ST_WLAN: R9.1, U5.11 (IO18)
/ESP32/TRG1: R10.1, R15.1, U5.4 (IO4)
/ESP32/TRG2: R11.1, R14.1, U5.5 (IO5)
/ESP32/TX: R21.2, U5.37 (TXD0)
/ESP32/XTAL_32K_N: C18.1, U5.9 (IO16), Y1.2
/ESP32/XTAL_32K_P: C14.1, U5.8 (IO15), Y1.1
/ESP32/~CS: U5.22 (IO14), U6.1 (~CS)
DG+: U5.14 (USB_D+); also elsewhere on the board
DG-: U5.13 (USB_D-); also elsewhere on the board
GND: C12.2, C13.2, C14.2, C15.2, C16.2, C17.2, C18.2, C19.1, D3.1 (K), D4.1 (K), D5.2 (A), D6.2 (A), D7.2 (A), D8.2 (A), D9.2 (A), J2.3, J3.3, SW1.2, SW2.2, U5.1 (GND), U5.40 (GND), U5.41 (GND), U6.4 (GND); also elsewhere on the board
unnamed: D3.2 (A), R8.2
unnamed: D4.2 (A), R9.2
unnamed: D5.1 (K), J2.2, R14.2
unnamed: D6.1 (K), J2.1, R15.2
unnamed: D7.1 (K), J2.5, R16.2
unnamed: D8.1 (K), J2.6, R17.2
unnamed: J3.1, R21.1
unnamed: J3.2, R22.1
unnamed: R19.2, U6.7 (~HOLD/~RESET/IO_{3})
unnamed: R20.2, U6.3 (~WP/IO_{2})
R_CTR: U5.31 (IO38); also elsewhere on the board
SCL: R7.1, U5.38 (IO2); also elsewhere on the board
SDA: R6.1, U5.39 (IO1); also elsewhere on the board
V3.3: C12.1, C13.1, C19.2, D9.1 (K), J2.4, R6.2, R7.2, R10.2, R11.2, R12.2, R13.2, R18.1, R19.1, R20.1, U5.2 (3V3), U6.8 (VCC); also elsewhere on the board

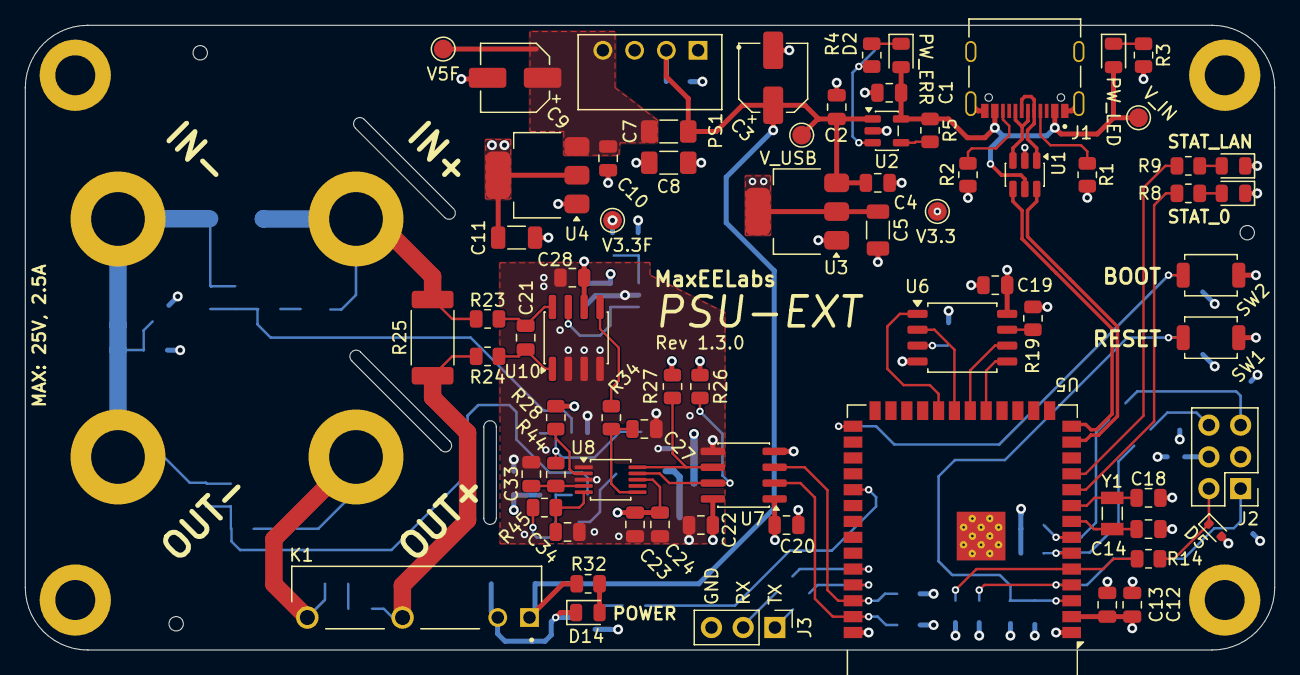
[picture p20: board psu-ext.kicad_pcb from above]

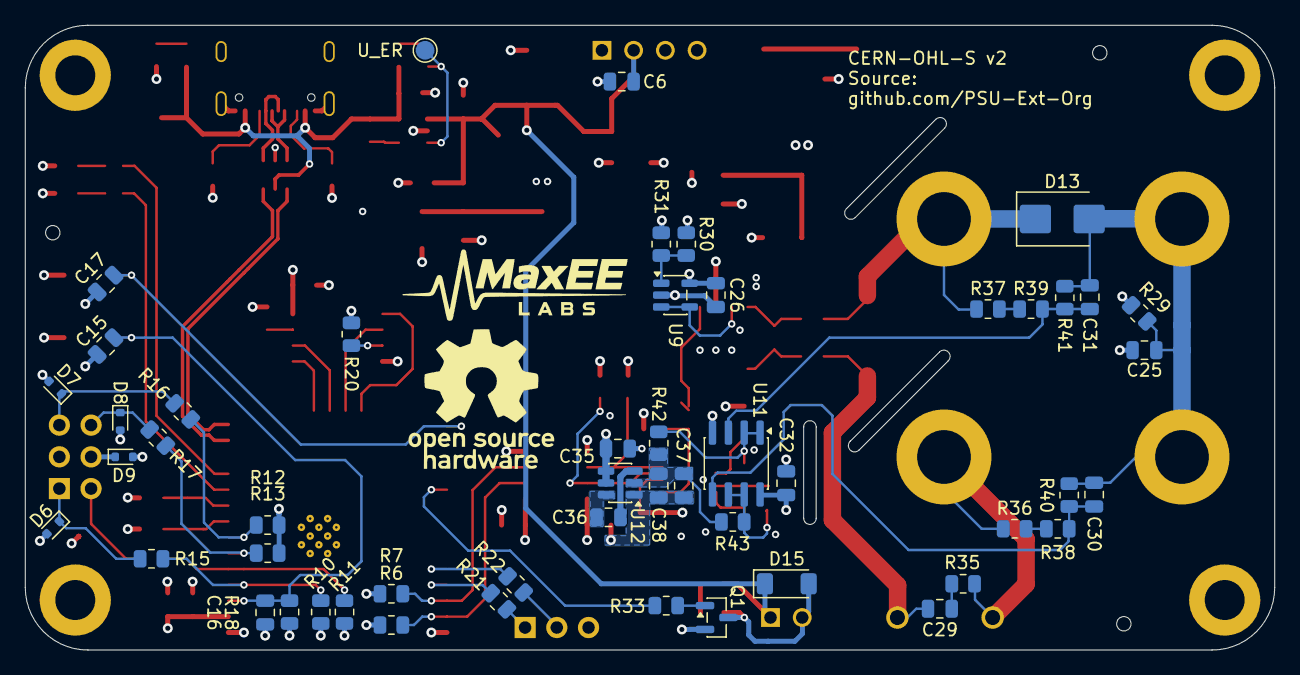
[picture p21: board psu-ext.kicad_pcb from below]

Board: 4 copper layers, 100.0 x 50.0 mm, 135 parts (53 on the bottom side), 74 nets.

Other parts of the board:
G1: LOGO; logo_oshw_22x13.2mm
G2: LOGO; logo_20x11.2mm

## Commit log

2026-08-17 Add current-sense amplifier offset and fix first-boot download mode
    Improve measurement accuracy near zero and enable bidirectional current sensing by adding the current-sense amplifier offset.
    Resolve the download-mode issue encountered on first boot.
    [BOM-psu-ext.csv, esp32.kicad_sch, front-end.kicad_sch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]
2026-09-27 Added input buffernig and negative rail for near-zero measurments (#2)
    * Added input buffernig and negative rail for near-zero measurments
    * Added I2C_NUM_1 on IO6 (SDA) and IO7 (SCL).
    * Feature/housing improvement (#3)
    * Fuse enclosure bottom covers and position terminal nuts
    * Top enclosure cleanup
    * Changed cover-top-left to reflect new pin header position and size
    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
    [BOM-psu-ext.csv, bs-joined-frame-bottom.3mf, esp32.kicad_sch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]
2026-10-26 Added IO3 pullup and negative 3V3 rail testpoint, few other PCB laypu… (#4)
    * Added IO3 pullup and negative 3V3 rail testpoint, few other PCB layput improvements.
    * Updated exports - gerbers, schematics, bom, CPL KiCad for version 1.3.1
    ---------
2026-10-29 Replaced USB power switch and refreshed manufacturing exports (#5)
    Replaced USB power switch U2 with AP2151DWG-7 (0.8 A). Updated schematic and PCB revision metadata and regenerated the BOM, CPL, schematic PDF, and Gerbers.
    Updated CHANGES.txt with the design changes and removed completed export TODOs.

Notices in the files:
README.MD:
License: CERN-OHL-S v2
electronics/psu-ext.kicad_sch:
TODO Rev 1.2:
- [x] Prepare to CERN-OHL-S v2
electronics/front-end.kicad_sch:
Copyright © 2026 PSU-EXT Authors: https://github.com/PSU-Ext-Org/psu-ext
